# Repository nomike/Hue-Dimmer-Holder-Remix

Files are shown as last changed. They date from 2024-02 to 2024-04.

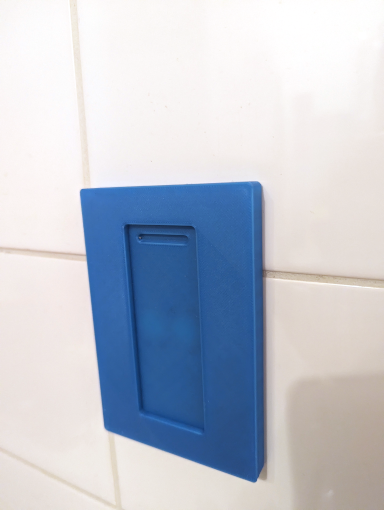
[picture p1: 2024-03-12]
photos/holder.png

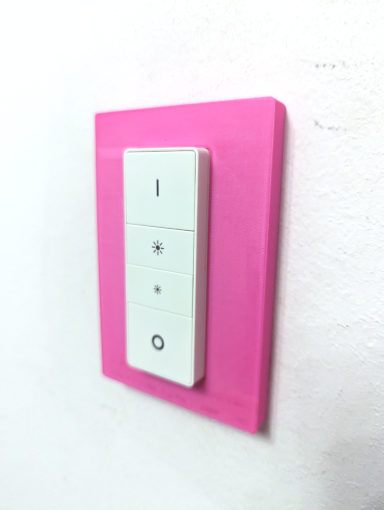
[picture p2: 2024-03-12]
photos/holder_with_remote.png

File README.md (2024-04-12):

A remix of <https://www.printables.com/model/148770-hue-dimmer-holder>.

The original design had some issues for me: The magnets didn´t hold the dimmer in place strong enough and the slope in the insert made the dimmer slide out of the holder when you operate it.

This remix removes the slopes from the insert, which completely resolves the issue of the remote slipping out. I also made the holes for the magnets a bit deeper, so that the magnets are closer to the dimmer switch, which should increse their holding force. I added a slope to those holes, so that the magnets could be removed more easily.

The original wall mount is relying on the wall boxes to be mounted absolutely level and flush to the wall. As this is not the case in my flat, I did not use it and decided to use double sided tape instead. I didn't touch the connector holes though, so even this remiced design should still work with the original wall mount if you prefer.

The script directly imports the original STL file and manipulates the object within, so I included it in the repository. The original file is licensed under the Creative Commons 4.0 - Attribution - NonCommercial license and can be downloaded via the link above.

#### Magnets

You can reuse the magnets from the original holder (a small flat-head screwdriver worked OK to pry them out).
I bought new ones (I used 15x2mm magnets as in the original holders) so I could double them to increase holding force.

I have since optimized the design, removing the gap between the remote and the magnets and made it harder for the remots to accidentally slide out of the holder. So this might no longer be necessary. I have however not tested the new design with a single set of magnets.

The orientation of the magnets doesn't seem to matter at all.

#### Thingiverse

<https://www.thingiverse.com/thing:6528330>

#### GitHub

<https://github.com/nomike/hue-dimmer-holder-remix>

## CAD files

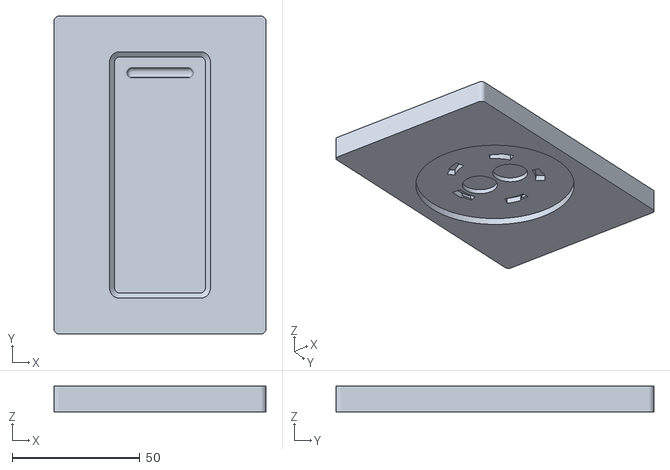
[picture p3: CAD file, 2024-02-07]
Hue Dimmer Holder.stl
83.0 x 124.5 x 10.0

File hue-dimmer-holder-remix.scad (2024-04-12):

/*
Hue Dimmer Holder Remix

Copyright 2024 nomike[AT]nomike[DOT]com

Redistribution and use in source and binary forms, with or without
modification, are permitted provided that the following conditions are met:

1. Redistributions of source code must retain the above copyright notice, this
list of conditions and the following disclaimer.

2. Redistributions in binary form must reproduce the above copyright notice,
this list of conditions and the following disclaimer in the documentation
and/or other materials provided with the distribution.

THIS SOFTWARE IS PROVIDED BY THE COPYRIGHT HOLDERS AND CONTRIBUTORS “AS IS” AND
ANY EXPRESS OR IMPLIED WARRANTIES, INCLUDING, BUT NOT LIMITED TO, THE IMPLIED
WARRANTIES OF MERCHANTABILITY AND FITNESS FOR A PARTICULAR PURPOSE ARE
DISCLAIMED. IN NO EVENT SHALL THE COPYRIGHT HOLDER OR CONTRIBUTORS BE LIABLE FOR
ANY DIRECT, INDIRECT, INCIDENTAL, SPECIAL, EXEMPLARY, OR CONSEQUENTIAL DAMAGES
(INCLUDING, BUT NOT LIMITED TO, PROCUREMENT OF SUBSTITUTE GOODS OR SERVICES;
LOSS OF USE, DATA, OR PROFITS; OR BUSINESS INTERRUPTION) HOWEVER CAUSED AND ON
ANY THEORY OF LIABILITY, WHETHER IN CONTRACT, STRICT LIABILITY, OR TORT
(INCLUDING NEGLIGENCE OR OTHERWISE) ARISING IN ANY WAY OUT OF THE USE OF THIS
SOFTWARE, EVEN IF ADVISED OF THE POSSIBILITY OF SUCH DAMAGE.
*/

union() {
    difference() {
        union() {
            // base part
            difference() {
                import("Hue Dimmer Holder.stl");
                color("red") translate([-50, -74, 8.05]) cube([100, 150, 10]);
            }

            // top part
            translate([0, 0, 8]) scale([1, 1, 2]) translate([0,0,-7.05]) intersection() {
                import("Hue Dimmer Holder.stl");
                color("red") translate([-50, -74, 7.05]) cube([100, 150, 1]);
            }
        }

        // holes for magnets
        translate([8.5, 0, 0]) color("orange") cylinder(d1=21, d2=15.5, h=6, $fn=75);
        translate([-8.5, 0, 0]) color("orange") cylinder(d1=21, d2=15.5, h=6, $fn=75);
    }
}

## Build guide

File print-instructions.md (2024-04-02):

Organic supports work well on this design. Use a small flat-head screwdriver to pry them off as one piece.

If you have a multi-head printer like the Prusa XL, you can also print the top-layer of the supports with a different material, so they are easier to remove (e.g. holder in PLA, top layer of supports in PETG).

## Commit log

2024-02-08 Reduce top part height.
    [Hue Dimmer Holder Remix.scad]
2024-03-12 Rename source file.
    [hue_dimmer_holder_remix.scad]
2024-04-02 Add print instructions.
2024-04-02 Add sections about magnets to readme.
2024-04-09 Switch to BSD-2-Clause license.
2024-04-12 Add license comment to OpenSCAD file.
    [hue_dimmer_holder_remix.scad]
2024-04-12 Rname OpenSCAD file for consistency reasons.
    [hue-dimmer-holder-remix.scad]
